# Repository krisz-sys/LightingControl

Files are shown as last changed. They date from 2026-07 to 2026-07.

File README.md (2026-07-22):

How it works?

The ESP8266 runs a web server. The microcontroller controls LED lighting and an electric valve.

The microcontroller handles the following tasks:
  The user can adjust the LED lighting using either the slider or the potentiometer.
  The valve was controlled based on the temperature measured on the radiator

You can access the web server by entering the IP address into your browser: http://192.168.1.230/ .
Additionally, you need to configure the WiFi SSID and password.

You can see the circuit schematic below:

<br>
Schematic
<br>
Here is the PCB layout:
<br>
pcb
<br>
You can find the AutoCAD Eagle design files as LightController_PCB.

If the web server is live, you should see the following view. The most important elements are the slider, the temperature value:
<br>
webserver

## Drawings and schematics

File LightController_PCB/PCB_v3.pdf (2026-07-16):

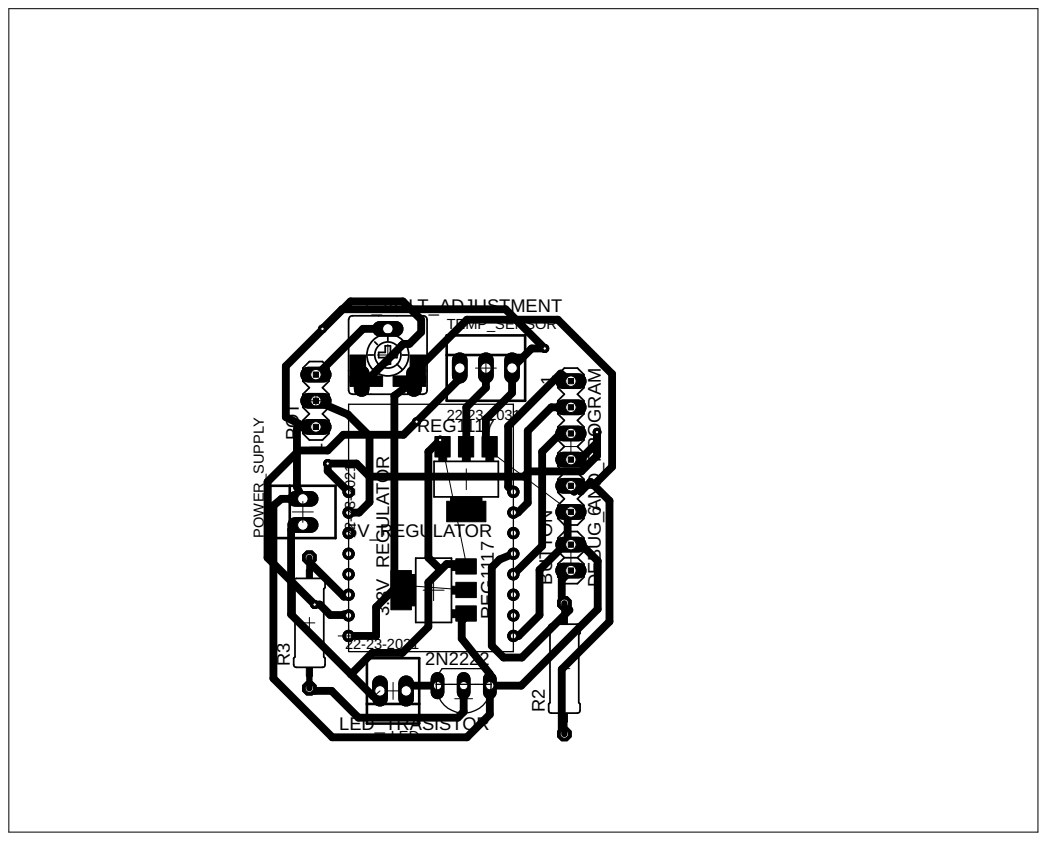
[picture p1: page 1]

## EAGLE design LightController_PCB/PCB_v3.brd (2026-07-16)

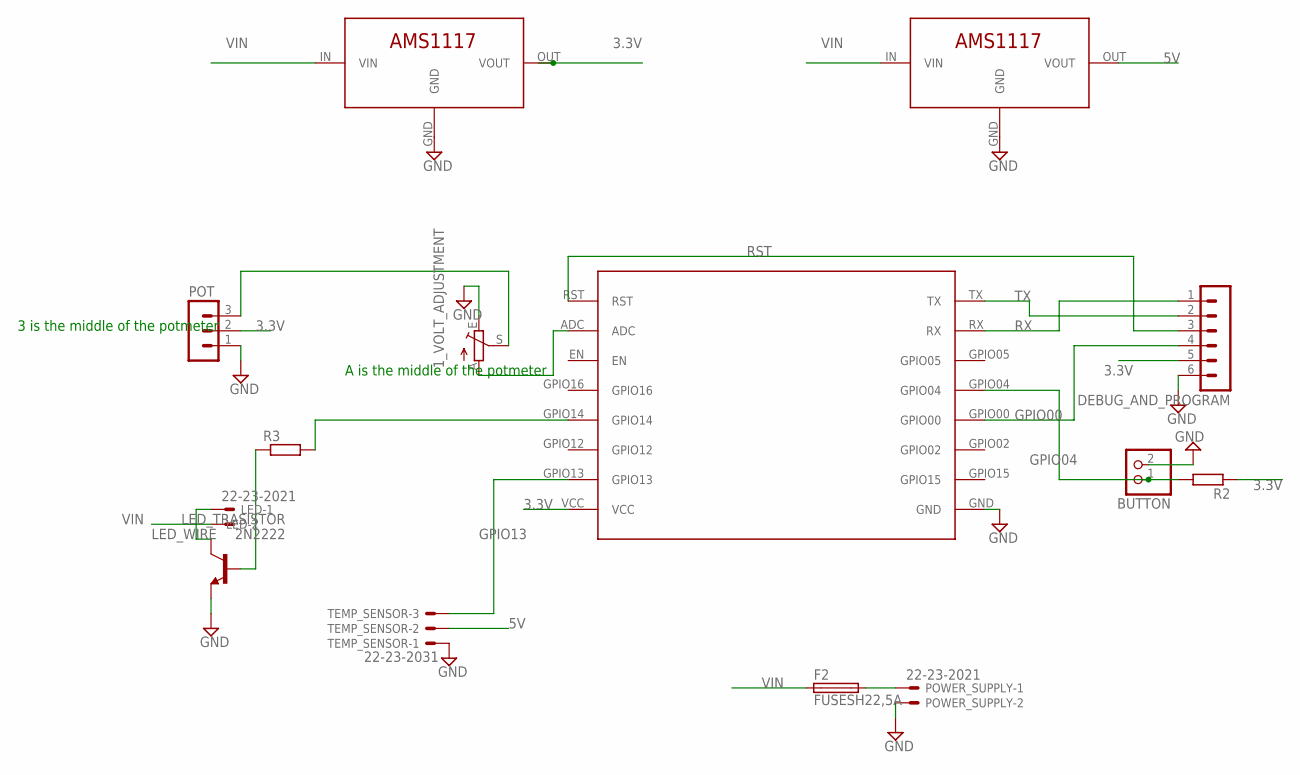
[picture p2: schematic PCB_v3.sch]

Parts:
1_VOLT_ADJUSTMENT: TRIM_EU-CA6V; CA6V
3.3V_REGULATOR, 5V_REGULATOR: AMS1117
BUTTON: PINHD-1X2; 1X02
DEBUG_AND_PROGRAM: MA06-1
F2: FUSESH22,5A; SH22,5A
LED: 22-23-2021
LED_TRASISTOR: 2N2222
POT: MA03-1
POWER_SUPPLY: 22-23-2021
R2, R3: R-EU_0309/12; 0309/12
TEMP_SENSOR: 22-23-2031
U$1: ESP8266

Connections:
3.3V: 3.3V_REGULATOR.OUT (VOUT), DEBUG_AND_PROGRAM.5, POT.2, R2.1, U$1.VCC
5V: 5V_REGULATOR.OUT (VOUT), TEMP_SENSOR.2
GND: 1_VOLT_ADJUSTMENT.E, 3.3V_REGULATOR.GND, 5V_REGULATOR.GND, BUTTON.2, DEBUG_AND_PROGRAM.6, LED_TRASISTOR.E, POT.1, POWER_SUPPLY.2, TEMP_SENSOR.1, U$1.GND
GPIO00: DEBUG_AND_PROGRAM.4, U$1.GPIO00
GPIO04: BUTTON.1, R2.2, U$1.GPIO04
GPIO13: TEMP_SENSOR.3, U$1.GPIO13
LED_WIRE: LED.1, LED_TRASISTOR.C
unnamed: 1_VOLT_ADJUSTMENT.A, U$1.ADC
unnamed: 1_VOLT_ADJUSTMENT.S, POT.3
unnamed: F2.2, POWER_SUPPLY.1
unnamed: R3.2, U$1.GPIO14
unnamed: LED_TRASISTOR.B, R3.1
RST: DEBUG_AND_PROGRAM.3, U$1.RST
RX: DEBUG_AND_PROGRAM.1, U$1.RX
TX: DEBUG_AND_PROGRAM.2, U$1.TX
VIN: 3.3V_REGULATOR.IN (VIN), 5V_REGULATOR.IN (VIN), F2.1, LED.2

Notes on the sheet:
3 is the middle of the potmeter
A is the middle of the potmeter

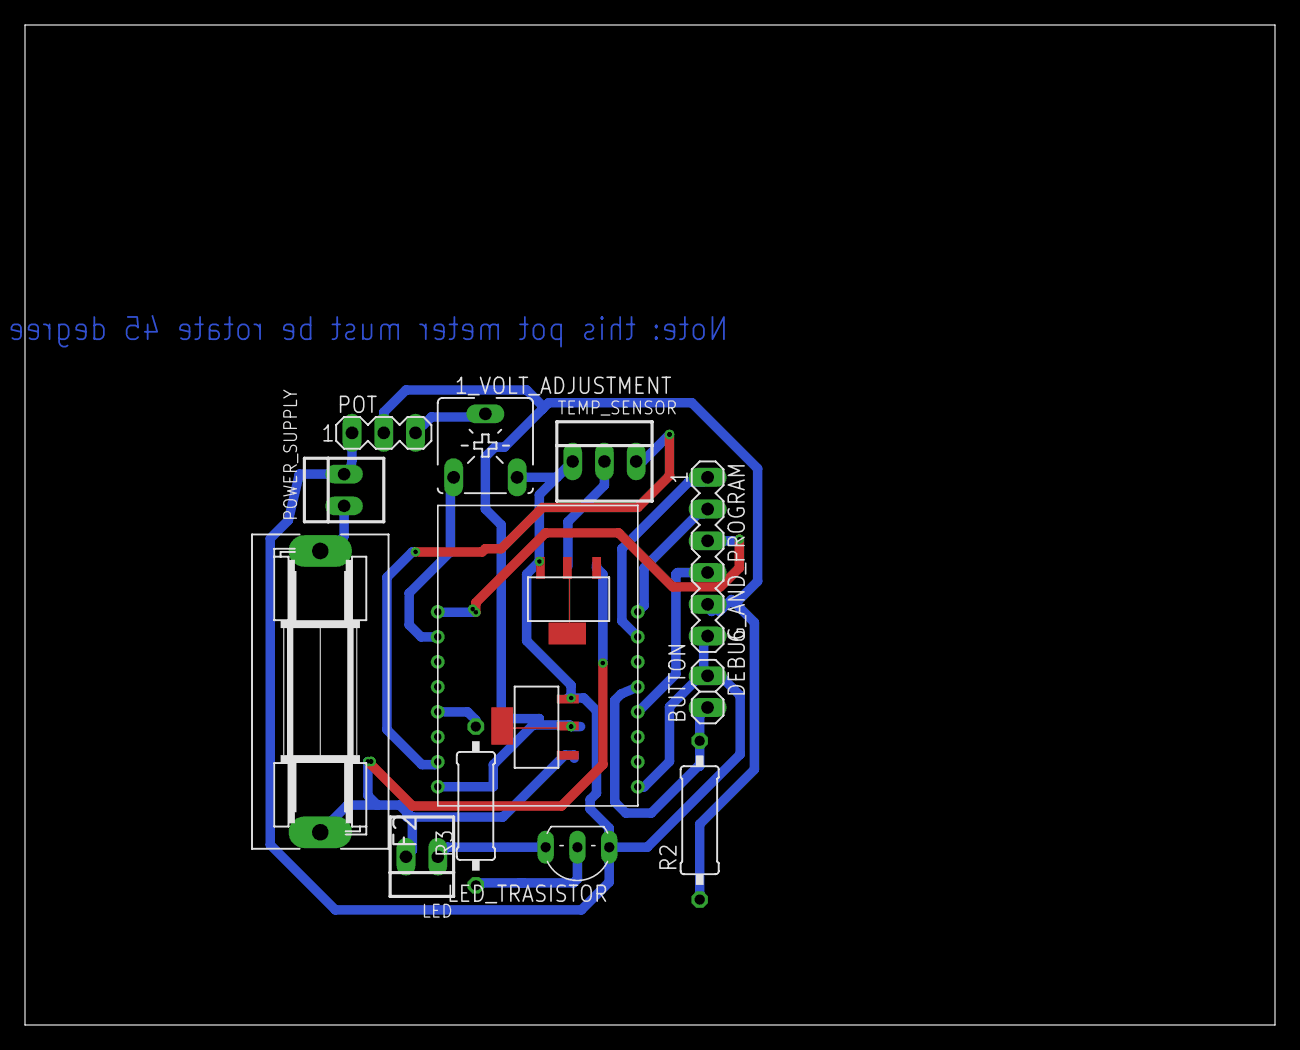
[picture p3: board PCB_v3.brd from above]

Board: 2 copper layers, 100.0 x 80.0 mm, 14 parts (0 on the bottom side), 16 nets.

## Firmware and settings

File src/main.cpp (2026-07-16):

#include <Arduino.h>

#include <ESP8266WiFi.h>
#include <NTPClient.h>
#include <WiFiUdp.h>
#include <String.h>
#include "DHT.h"
//#include "time.h"
#include <ModbusIP_ESP8266.h>
#include <ArduinoOTA.h>
#include <ESPAsyncWebServer.h>
#include <ESPAsyncTCP.h>
#include <ArduinoJson.h>




#include "index.h"
// -------------------------------------- NTP server

WiFiUDP ntpUDP;
NTPClient timeClient(ntpUDP);
String formattedDate;
String dayStamp;
String timeStamp;
long date_check_timer;
//--------------------------------------  UDP communication
unsigned int localUdpPort = 9800;
char incomingPacket[200];                               // buffer for incoming packets
char respond[200];
WiFiUDP Udp;
//char* remoteIp="";
//--------------------------------------- temp, humidity 
#define DHTPIN D7              // GPIO13
#define DHTTYPE DHT11
DHT dht(DHTPIN, DHTTYPE);
int humidity=-10;
float temperature=-10;
// --------------------------------------- comm protocol
#define COMM_ERR 56
#define TEMP_REQUEST 39
#define TEMP_FLAG 40
#define HUM_REQUEST 41
#define HUM_FLAG 42
#define TEMP_SENSOR_ERROR 55
#define MSG_RECEIVED 65
#define SET_LED 66
#define LED_REQUEST 67
#define SEND_BACK_LED 68
#define HUM_SENSOR_ERR 101                // the humidity sensor is damaged or don t works
#define BOSS 50
//---------------------------------------- led
#define LED D5                             // GPIO12
#define POT A0                              // potentiometer
#define VALVE D2
long unsigned potTimer;
int ledSPMode=1;                       // 0 => led SP from the POT,       1 => led SP from the sender,      2 => light increasing and decreasing
int lastSample=0;
bool firstStart=true;
int requestedVal=0;
//----------------------------------------wifi

const char *ssid = "yourSSID";          //Enter your wifi SSID
const char *password = "yourPassword";        //Enter your wifi Password
IPAddress local_IP(192, 168, 1, 230);       // a telefonba ezt az ip-t kell beírni
IPAddress gateway(192, 168, 1, 1);
IPAddress subnet(255, 255, 255, 0);
IPAddress primaryDNS(8, 8, 8, 8);           //optional
IPAddress secondaryDNS(8, 8, 4, 4);

#define debug(x) Serial.print(x)
#define debugln(x) Serial.println(x)
float myPWM=0;                                  
long PWM_period=4000;                               // period of the PWM                     
int up_limit=0.95*PWM_period;                        // above this value the LED should turn ON

long unsigned reconnect_period=120*1000;
long  reconnectTimer;
long  tempSampleTimer;
long ledTurnedOffTimer;

float ledVal=0;

// ---------------------------------pot sampling
int maxSample=6;
int maxValue=0;
int sampleNum=0;
int sampleCounter=0;
double *potBuffer=(double*)malloc(sizeof(double)*maxSample);             // the samples are saved here
int currentPotAVG;

// ----------------------------------errors
bool isError=false;
long curentBlinkingPeriod=5000;
int networkError=5000;
long tempSamplePeriod=30000;
long serverUpdatePeriod=300;
long valveHandlePeriod=5000;
long errorTimer;
long serverUpdateTimer;
long valveHandleTimer;
bool ledState=false;
bool disablePotmeter=false;

int hystUpperLimit=35;
int hystLowerLimit=30;

signed int potChanging=0;

String sliderValue = "0";

const char* PARAM_INPUT = "value";

// Create AsyncWebServer object on port 80
AsyncWebServer server1(80);
AsyncWebSocket ws("/ws"); 


// Function to send value updates to clients
void notifyClients() {
  String finalString=String(float(requestedVal)/5.6)+", "+String(temperature,1);

  ws.textAll(finalString);  // send value to all connected clients
  
}

// Handle incoming WebSocket messages (optional)
void onWebSocketMessage(void *arg, uint8_t *data, size_t len) {
  AwsFrameInfo *info = (AwsFrameInfo*)arg;

  if (info->final && info->index == 0 && info->opcode == WS_TEXT) {

    // Safe copy
    char message[len + 1];
    memcpy(message, data, len);
    message[len] = 0;

    String msg = String(message);
    Serial.println("Received: " + msg);

    // Expecting message like: "Slider: 234"
  String prefix = "Slider: ";
    if (msg.startsWith(prefix)) {
      String sliderVal = msg.substring(prefix.length());

      float sliderValue = sliderVal.toFloat();
      requestedVal=int(sliderValue*5.6);
      //ledVal=sliderValue*5.6;
      ledSPMode=1;

      Serial.println("Parsed slider value: " + sliderVal);
    }
    prefix = "Button: ";
    if (msg.startsWith(prefix)) {
      String buttonVal = msg.substring(prefix.length());

      if(buttonVal.equals("ON")){
        //digitalWrite(VALVE,1);
      }
      else{
          //digitalWrite(VALVE,0);
      }

      Serial.println("Parsed button value: " + buttonVal);
    }


  }
  /*
  AwsFrameInfo *info = (AwsFrameInfo*)arg;

  if (info->final && info->index == 0 && info->opcode == WS_TEXT) {

    // Safe copy
    char message[len + 1];
    memcpy(message, data, len);
    message[len] = 0;

    String msg = String(message);
    Serial.println("Received: " + msg);

    // Expecting message like: "Slider: 234"
    String prefix = "Slider: ";

    prefix = "Button: ";

    if (msg.startsWith(prefix)) {
      String buttonVal = msg.substring(prefix.length());
      Serial.println("Button value: " + buttonVal);
    }

  }
  */
  
}

void onWebSocketEvent(AsyncWebSocket *server, AsyncWebSocketClient *client, 
                      AwsEventType type, void *arg, uint8_t *data, size_t len) {
  if (type == WS_EVT_CONNECT) {
    Serial.printf("Client #%u connected\n", client->id());
  } else if (type == WS_EVT_DISCONNECT) {
    Serial.printf("Client #%u disconnected\n", client->id());
  } else if (type == WS_EVT_DATA) {
    onWebSocketMessage(arg, data, len);
  }
}


//--------------------------------------- modbus variables
ModbusIP mb;

int PotValueAddr=0;
int RequestedValAddr=1;
int LedSPModeAddr=2;
int AvaragePotSampleAddr=3;
int LedValAddr=4;
int TempAddr=5;
int HumAddr=6;
int MaxPotAddr=7;


void sliderRequest(AsyncWebServerRequest *request);
 void temp1Request(AsyncWebServerRequest *request);
 void connect2Wifi(int max_attempts);
 void ledHandler();
 void decodeAndBuildRespond();
 void getTime();
void sendUDP();
void readHumAndTemp();
bool temp2bytes(char*tempBytes);
void calculateMax();
double calculateAvarage();
void setAll(int val);


void setup() {
  Serial.begin(9600);

  dht.begin();
  analogWriteFreq(75); 
  pinMode(LED,OUTPUT);
  pinMode(VALVE,OUTPUT);
  pinMode(POT,INPUT);
  
  pinMode(LED_BUILTIN, OUTPUT);
  if (!WiFi.config(local_IP, gateway, subnet, primaryDNS, secondaryDNS)) {
    Serial.println("STA Failed to configure");
  }
  debugln("");
  Serial.printf("Connecting to %s ", ssid);
  WiFi.mode(WIFI_STA);
  WiFi.begin(ssid, password); //Connect to wifi
  
  connect2Wifi(200);
  timeClient.begin();
  timeClient.setTimeOffset(3*3600);
  Udp.begin(localUdpPort);

  reconnectTimer=millis();
  potTimer=millis();
  date_check_timer=millis();               
  errorTimer=micros();
  tempSampleTimer=millis();
  serverUpdateTimer=millis();
  ledTurnedOffTimer=millis();
  // ---------------------------------- webserver

  server1.on("/", HTTP_GET, [](AsyncWebServerRequest *request){
    request->send_P(200, "text/html; charset=utf-8",index_html);
  });
  ws.onEvent(onWebSocketEvent);
  server1.addHandler(&ws);
  server1.begin();


  //---------------------------------- OTA

// Port defaults to 8266
  // ArduinoOTA.setPort(8266);

  // Hostname defaults to esp8266-[ChipID]
   ArduinoOTA.setHostname("ESP8266-LED controller");

  // No authentication by default
  ArduinoOTA.setPassword("admin");

  // Password can be set with it's md5 value as well
  // MD5(admin) = 21232f297a57a5a743894a0e4a801fc3
  // ArduinoOTA.setPasswordHash("21232f297a57a5a743894a0e4a801fc3");

  ArduinoOTA.onStart([]() {
    String type;
    if (ArduinoOTA.getCommand() == U_FLASH) {
      type = "sketch";
    } else {  // U_FS
      type = "filesystem";
    }

    // NOTE: if updating FS this would be the place to unmount FS using FS.end()
    Serial.println("Start updating " + type);
  });
  ArduinoOTA.onEnd([]() {
    Serial.println("\nEnd");
  });
  ArduinoOTA.onProgress([](unsigned int progress, unsigned int total) {
    Serial.printf("Progress: %u%%\r", (progress / (total / 100)));
  });
  ArduinoOTA.onError([](ota_error_t error) {
    Serial.printf("Error[%u]: ", error);
    if (error == OTA_AUTH_ERROR) {
      Serial.println("Auth Failed");
    } else if (error == OTA_BEGIN_ERROR) {
      Serial.println("Begin Failed");
    } else if (error == OTA_CONNECT_ERROR) {
      Serial.println("Connect Failed");
    } else if (error == OTA_RECEIVE_ERROR) {
      Serial.println("Receive Failed");
    } else if (error == OTA_END_ERROR) {
      Serial.println("End Failed");
    }
  });
  ArduinoOTA.begin();
  Serial.println("Ready");

  // ------------------------------ modbus
  mb.server();            // default modbus port 502
  mb.addHreg(PotValueAddr, 0);              // 0
  mb.addHreg(RequestedValAddr, 0);          // 1
  mb.addHreg(LedSPModeAddr, 0);             // 2
  mb.addHreg(AvaragePotSampleAddr, 0);      // 3
  mb.addHreg(LedValAddr, 0);                // 4
  mb.addHreg(TempAddr, 0);                  // 5
  mb.addHreg(HumAddr, 0);                   // 6
  mb.addHreg(MaxPotAddr,0);                 // 7

  readHumAndTemp();
}

  void connect2Wifi(int max_attempts){
  int i=0;
  
  while (WiFi.status() != WL_CONNECTED)
  {
    delay(200);
    Serial.print(".");
    if(i>=max_attempts){
      debugln("");
      debug("localIP: ");
      debugln(WiFi.localIP());
      isError=true;
      curentBlinkingPeriod=networkError;
      return;
    }
    i++;
  }
  isError=false;
}


void ledHandler(){
  int currentSample=analogRead(POT);      // taking a sample
  mb.Hreg(PotValueAddr, currentSample);
  potBuffer[sampleCounter++]=currentSample;
  if(sampleCounter>maxSample-1){
    sampleCounter=0;
  }
  sampleNum++;
  if(sampleNum>maxSample){
    sampleNum=maxSample;
  }

  calculateMax();

  float avarageSample=(float)calculateAvarage();                  // avarage filter for preventing the unwanted led blinking
  currentPotAVG=avarageSample;
  mb.Hreg(AvaragePotSampleAddr, avarageSample);
  //------------------------- end of the sample handling
  
  mb.Hreg(LedSPModeAddr, ledSPMode);
  if(ledSPMode==0){                                           // control from potmeter
    if(avarageSample>8){
      ledVal=avarageSample;
      requestedVal=ledVal;
      analogWrite(LED,avarageSample);
    }
    else{
      ledVal=0;
      requestedVal=ledVal;
      analogWrite(LED,ledVal);
    }
  }
  else if(ledSPMode==1){                                      // control from the user
    int diff=ledVal-requestedVal;
    if(diff<0){
      diff*=-1;
    }

    if(diff!=0 && diff<=1){
      //ledVal=requestedVal;
      analogWrite(LED,requestedVal);
    }
    else if(ledVal-float(requestedVal)>1.0 && diff!=0){                 //positive difference
      ledVal-=3;
      //analogWrite(LED,ledVal*1.8);
      analogWrite(LED,ledVal);
    }
    else if(ledVal-float(requestedVal)<1.0 && diff!=0){                 //negative difference
      ledVal+=3;
      //analogWrite(LED,ledVal*1.8);
      analogWrite(LED,ledVal);
    }
  }
  
    
  if(firstStart){                                      // if the controller just started, the POT donsn't have priority
    lastSample=currentSample;
    firstStart=false;
  }
  int diff=currentSample-lastSample;
  if(diff>0){
    potChanging--;
  }
  else if(diff<0){
    potChanging++;
  }
  else{
    potChanging=0;
  }

  

  if(potChanging>20 || potChanging<-20){
    ledSPMode=0;
    setAll(currentSample);            // when the potentiometer is unes we want to prevent the initial delay

  }
  lastSample=currentSample;
  mb.Hreg(LedValAddr, ledVal);
  
}

void decodeAndBuildRespond(){
  
  debug("incoming:  ");
  for(int i=0;i<incomingPacket[0];++i){
    debug((byte)incomingPacket[i]);
    debug(" ");
  }
  debugln(" ");
  
  int i=0;                    // counter of the receiver packet
  int j=1;              // counter of the respond packet
  int len=incomingPacket[i++];
  //char respond[50];
  //debug("len: ");
  //debugln(len);
  debug("");
  while(1){
    if(i>=len){
      break;
    }
    byte b=(byte)incomingPacket[i++];
    debugln(b);
    if(b==TEMP_REQUEST){
      readHumAndTemp();
      char tempbytes[2];
      respond[j++]=TEMP_FLAG;
      if(temp2bytes(tempbytes)){
        respond[j++]=tempbytes[0];
        respond[j++]=tempbytes[1];
      }
      else{
        respond[j++]=TEMP_SENSOR_ERROR;
        respond[j++]=TEMP_SENSOR_ERROR;
      }
    }
    if(b==HUM_REQUEST){
      readHumAndTemp();
      respond[j++]=HUM_FLAG;
      if(humidity!=-10){
        respond[j++]=humidity;
      }
      else{
        respond[j++]=HUM_SENSOR_ERR;
      }
    }
    if(b==SET_LED){
      /*          //OLD
      ledVal=(byte)incomingPacket[i++];
      ledSPMode=true;
      analogWrite(LED,ledVal*10);
      */

      //requestedVal=(byte)incomingPacket[i++];
      requestedVal=incomingPacket[i++]*1.8;
      mb.Hreg(RequestedValAddr, requestedVal);
      ledSPMode=1;
      
      if(len==3){
        respond[j++]=MSG_RECEIVED;
      }
    }
    if(b==LED_REQUEST){
        respond[j++]=SEND_BACK_LED;
        respond[j++]=(byte)(mb.Hreg(LedValAddr)/1.8);
        debugln("led val requested");
      }
  }

  
  respond[j]='\0';
  respond[0]=j-1;
  debug("Byte code:  ");
  for(i=0;i<j;++i){
    debug((byte)respond[i]);
    debug(" ");
  }
  debugln(" ");
  debugln("");
  incomingPacket[0]=0;

  debugln(j);
    //int lengt=strlen(respond);
    for (int i=0;i<j;++i){
      respond[i]=(char)((int)respond[i]+1);
      debug((byte)respond[i]);
      debug(" ");
    }
  //return respond;
}

void getTime(){
  for (int i=0;i<3;++i){
    timeClient.forceUpdate();
    if(timeClient.update()){
      break;
    }
  }
  //formattedDate = timeClient.getFormattedDate();
  formattedDate = timeClient.getFormattedTime();
  

  // Extract date
  int splitT = formattedDate.indexOf("T");
  dayStamp = formattedDate.substring(0, splitT);
  
  timeStamp = formattedDate.substring(splitT+1, formattedDate.length()-4);

  Serial.println(formattedDate);
  Serial.print("DATE: ");
  Serial.println(dayStamp);
  Serial.print("HOUR: ");
  Serial.println(timeStamp);
}

int receiveUDP(){
  int packetSize = Udp.parsePacket();
  if (packetSize)
  {
    // receive incoming UDP packets
    //Serial.printf("Received %d bytes from %s, port %d\n", packetSize, Udp.remoteIP().toString().c_str(), Udp.remotePort());
    //const char* cRemIP=Udp.remoteIP().toString().c_str();
    //remoteIp=Udp.remoteIP();
    //const char* cRemIP=Udp.remoteIP();
    //debugln(typeid(Udp.remoteIP()).name());
    //strcpy(remoteIp,cRemIP);
    int len = Udp.read(incomingPacket, 255);
    debugln(len);
    debugln((int)incomingPacket[1]);
    if((int)incomingPacket[1]!=BOSS){
        return 0;
    }
    if (len > 0)
    {
      incomingPacket[len] = 0;
    }
    //Serial.printf("UDP packet contents: %s\n", incomingPacket);
  }
  return packetSize;
}

void sendUDP(){
    Udp.beginPacket(Udp.remoteIP(), localUdpPort);
    Udp.write(respond);
    Udp.endPacket();  


    debugln("");
    debug("remoteIP:  ");
    debugln(Udp.remoteIP());
    debug("respond:  ");
    
    for(int i=0;i<strlen(respond);++i){
      debug((byte)respond[i]);
      debug(" ");
    }
    
    debugln("");
}


void readHumAndTemp(){

  humidity = dht.readHumidity();
  float temp= dht.readTemperature();
  //temperature = dht.computeHeatIndex(temp, humidity, false);    

  temperature = dht.readTemperature()-5;

  if(isnan(humidity)){
    humidity=-10;
  }
  if(isnan(temperature)){
    temperature=-10;
  }
  
  mb.Hreg(HumAddr, humidity);
  mb.Hreg(TempAddr, temperature*10);
}

bool temp2bytes(char*tempBytes){
  if(temperature!=-10){
    double fractpart, intpart; 
    fractpart = modf (temperature , &intpart);
    tempBytes[0]=(char)intpart;
    tempBytes[1]=(char)(fractpart*100);
    return true;
  }
  return false;
}

void calculateMax(){
  //potBuffer[sampleCounter++]=currentSample;
  int max=0;
  for(int i=0;i<maxSample;++i){
    if(max<potBuffer[i]){
      max=potBuffer[i];
    }
  }
  maxValue=max;
  mb.Hreg(MaxPotAddr, maxValue);
}

double calculateAvarage(){
  double avarage=0;
  for(int i=0;i<sampleNum;++i){
    avarage+=potBuffer[i];
  }
  //Serial.println("");
  return avarage/sampleNum;
}
void setAll(int val){                       // when the potentiometer is unes we want to prevent the initial delay
  for(int i=0;i<sampleNum;++i){
    potBuffer[i]=val;
  }
}




void loop() {
  ArduinoOTA.handle();
  mb.task();
  
  /*
  if(receiveUDP()>0){
    //char*respond=decodeAndBuildRespond();
    decodeAndBuildRespond();
    //sendUDP(respond);
    sendUDP();
  }
  */

  if(millis()-potTimer>15){
      ledHandler();
      potTimer=millis();
      if(millis()-reconnectTimer>reconnect_period){
        reconnectTimer=millis();
        connect2Wifi(200);
      }
      if(millis()-date_check_timer>60000){
        getTime();
        if(strcmp(timeStamp.c_str(),"07:00")==0){
          debugln("restarting");
          ESP.restart();
        }
        date_check_timer=millis();
        
      }
      if(isError){
        if(millis()-errorTimer>curentBlinkingPeriod){
          errorTimer=millis();
          digitalWrite(LED_BUILTIN,ledState);
          ledState=!ledState;
        }
      }
      else{
        digitalWrite(LED_BUILTIN,1);
      }
      
      if(millis()-tempSampleTimer>tempSamplePeriod){
            tempSampleTimer=millis();
            readHumAndTemp();
      }

      if(millis()-serverUpdateTimer>serverUpdatePeriod){
        serverUpdateTimer=millis();
        notifyClients();
      }

      if(millis()-valveHandleTimer>valveHandlePeriod){
        valveHandleTimer=millis();
        if(temperature>hystUpperLimit){
          digitalWrite(VALVE,0);
        }
        else if(temperature<hystLowerLimit){
          digitalWrite(VALVE,1);
        }
      }

      if(currentPotAVG==0 && millis()-ledTurnedOffTimer>45000){
        if(ledSPMode==0){
          ledTurnedOffTimer=millis();
          ledSPMode=1;
        }
      }
    }
}
